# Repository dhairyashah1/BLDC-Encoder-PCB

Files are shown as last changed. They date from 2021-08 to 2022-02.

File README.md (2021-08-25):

# BLDC-Encoder-PCB

This repository contains KiCAD Design Files for Encoder PCB made using AS5600 hall sensor based Encoder Chip for [SRA-VJTI](https://github.com/SRA-VJTI/)'s BLDC Actuator and Quadraped Testing.

## Schematics
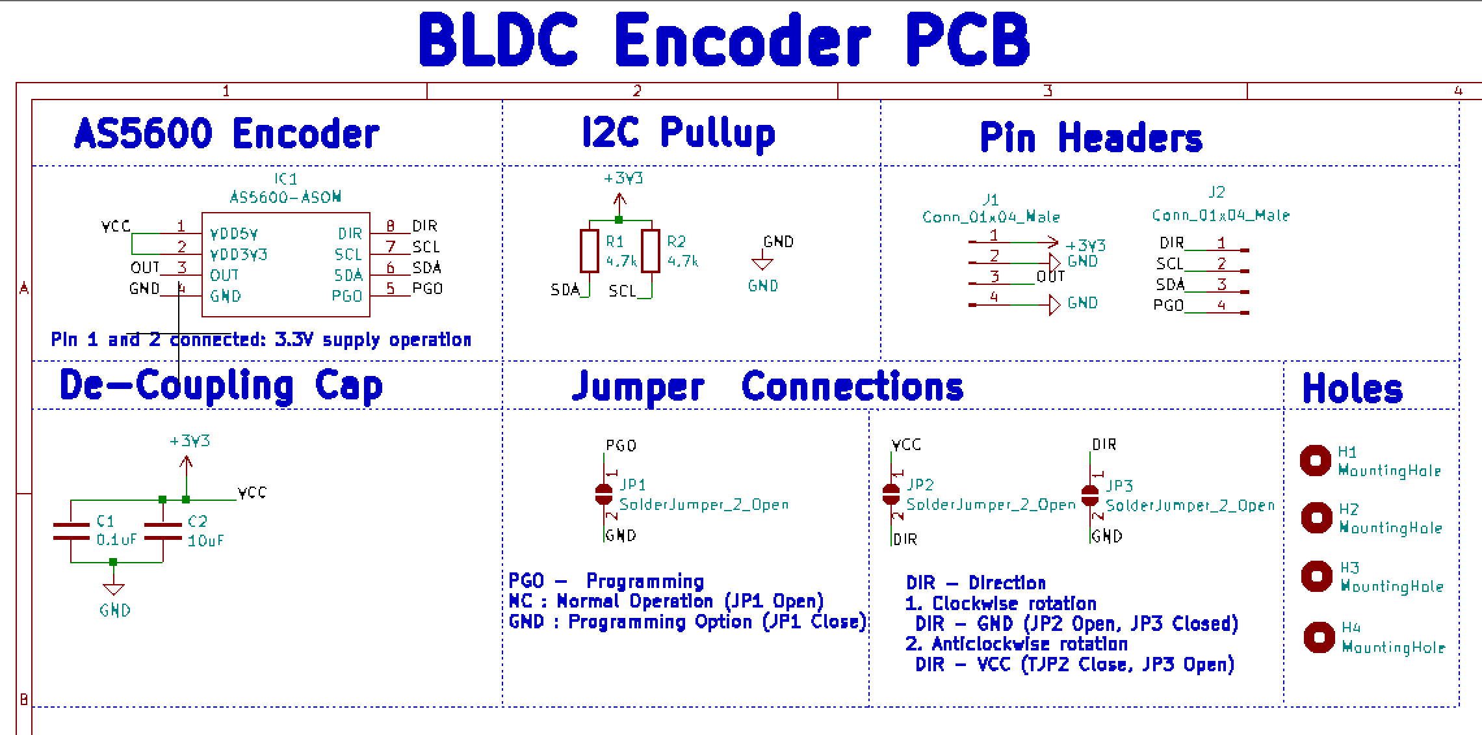
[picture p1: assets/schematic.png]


## Renders

### Front View
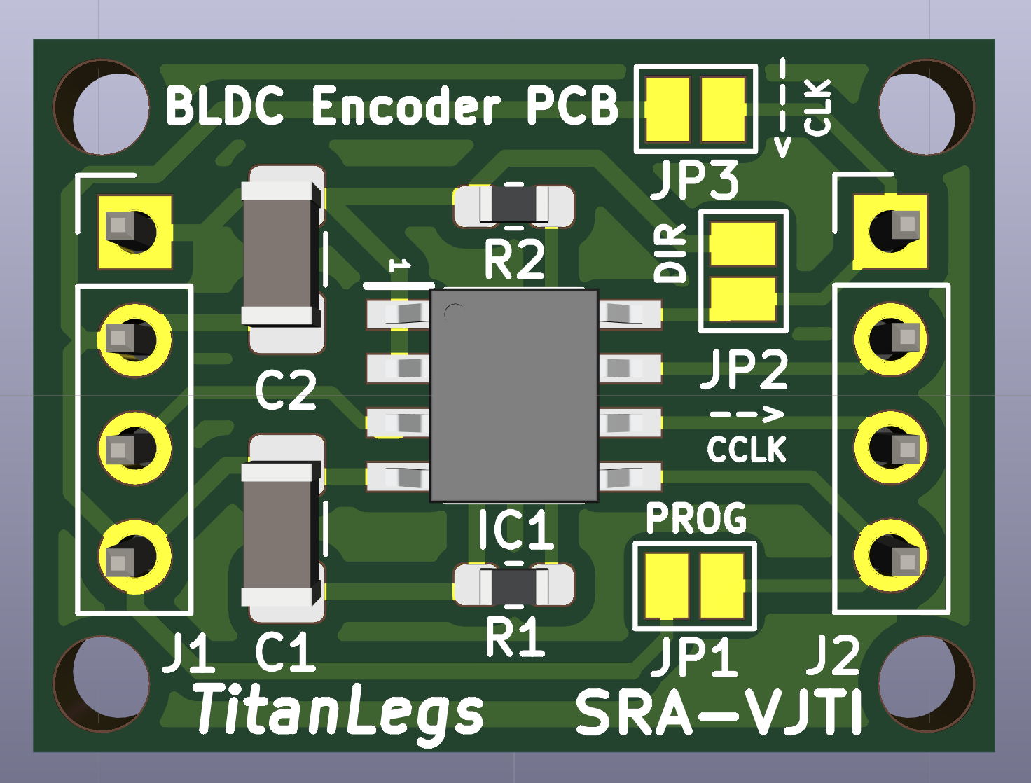
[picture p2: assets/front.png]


### General View
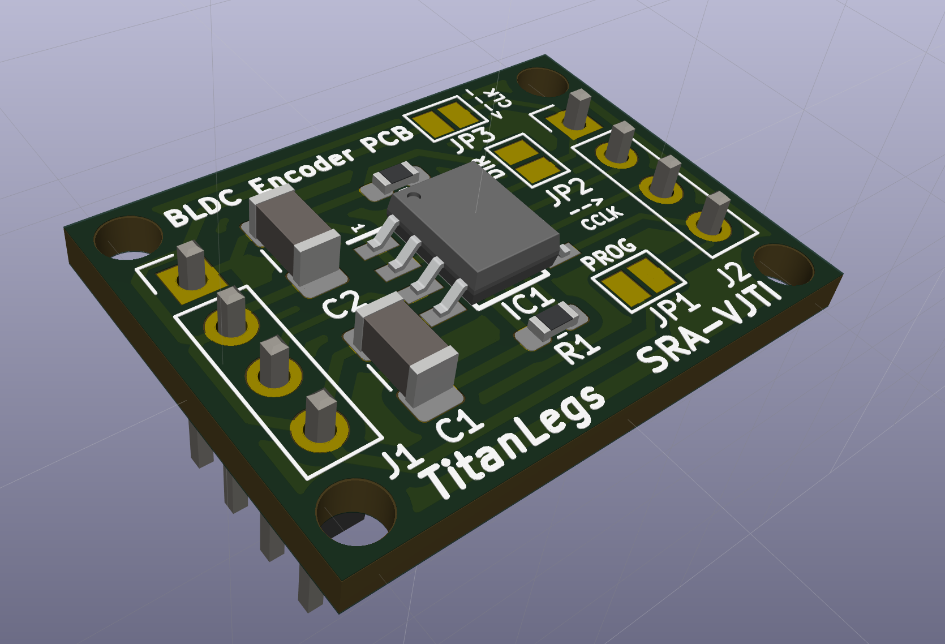
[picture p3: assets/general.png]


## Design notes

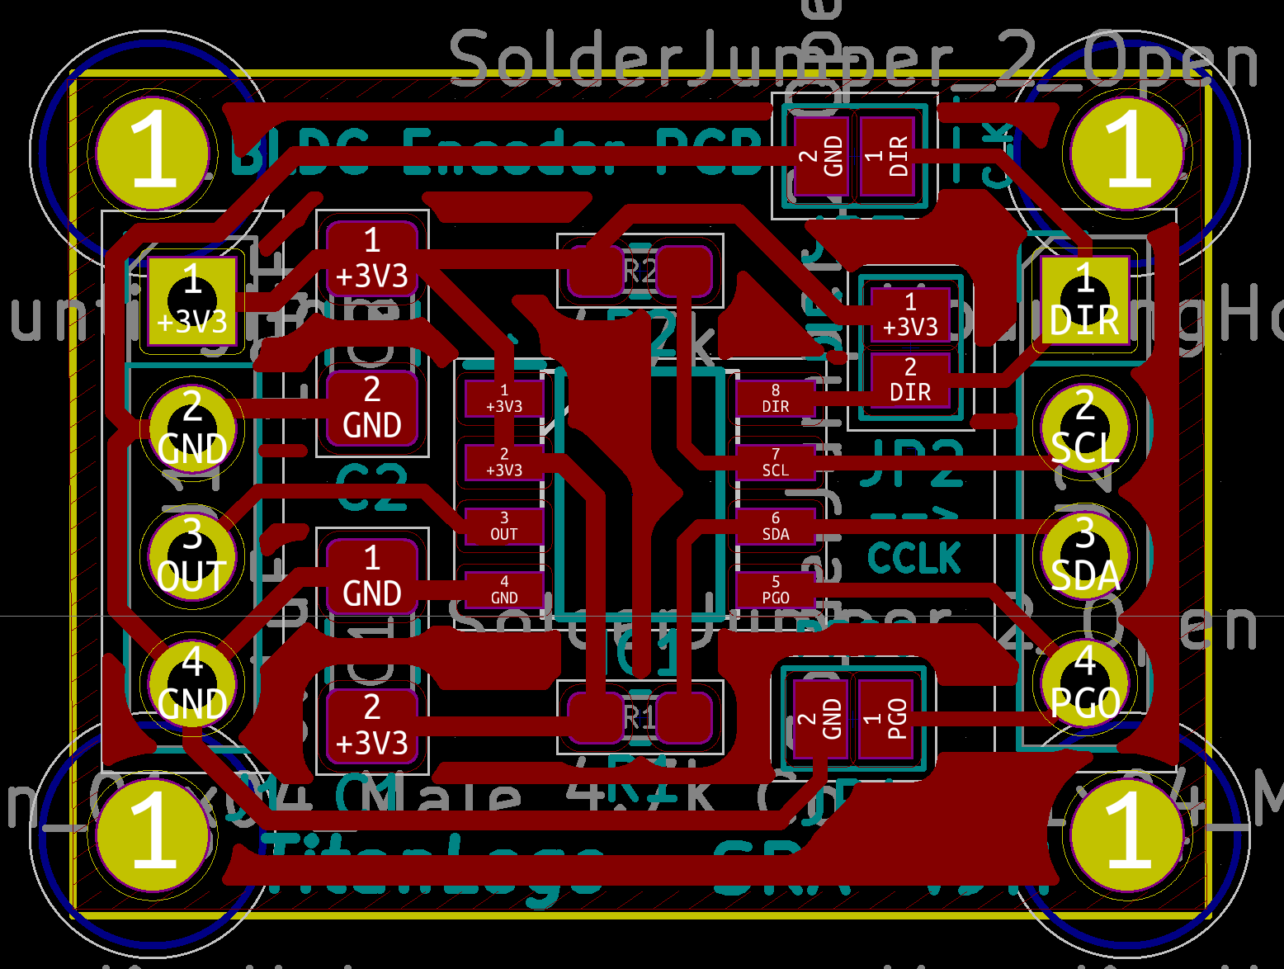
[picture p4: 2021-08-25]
assets/routing.png

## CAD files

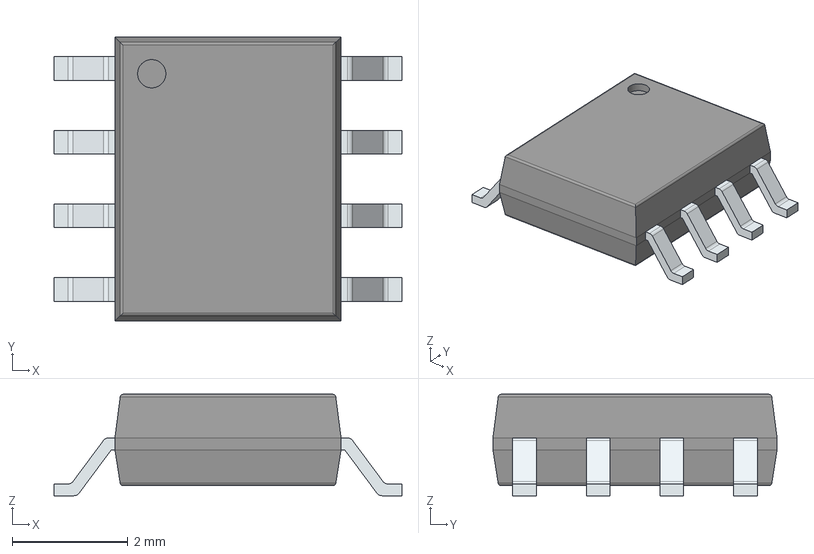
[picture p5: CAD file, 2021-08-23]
component_libraries/AS5600-ASOM/AS5600-ASOM.stp
6.00 x 4.90 x 1.75 mm
PinsArrayLR

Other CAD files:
component_libraries/AS5600-ASOM/AS5600-ASOM.stl

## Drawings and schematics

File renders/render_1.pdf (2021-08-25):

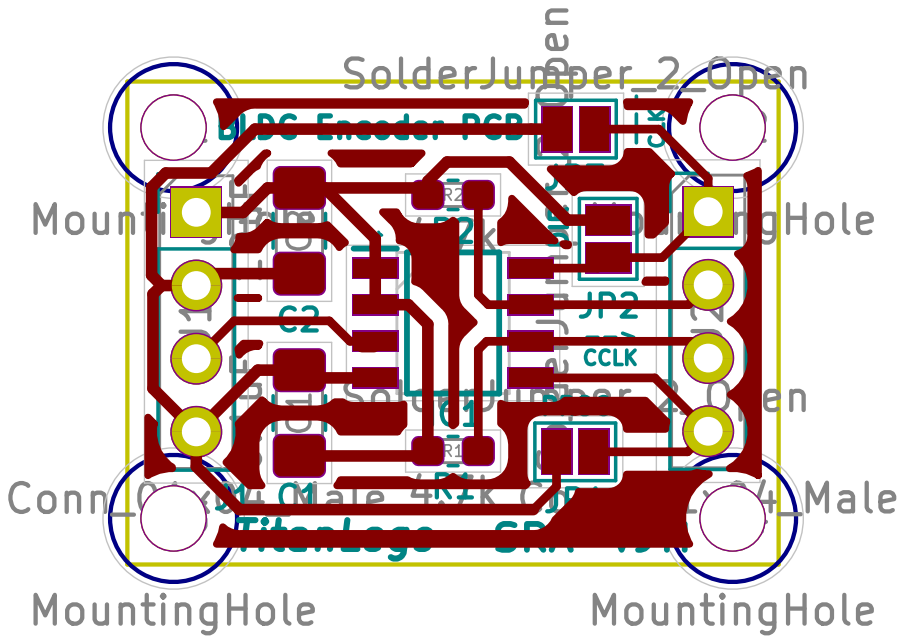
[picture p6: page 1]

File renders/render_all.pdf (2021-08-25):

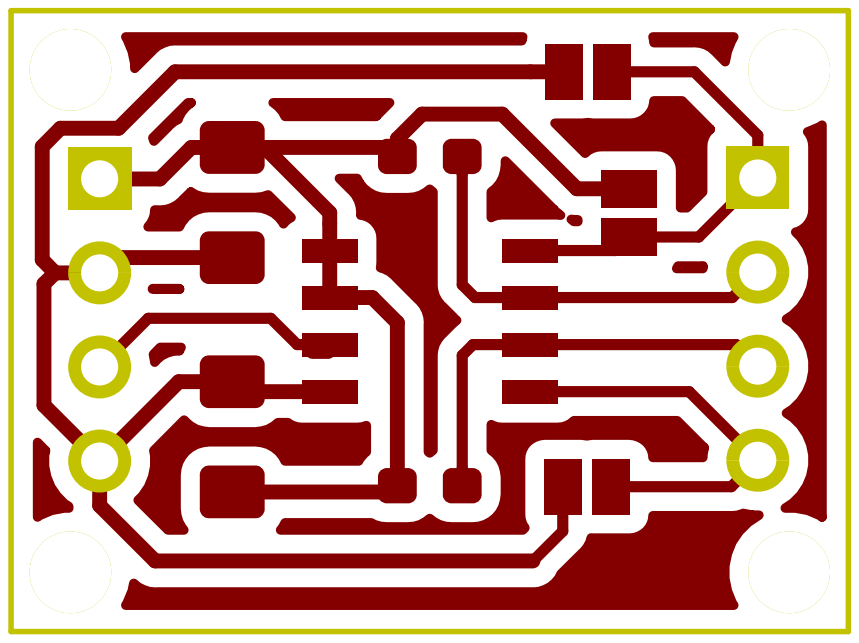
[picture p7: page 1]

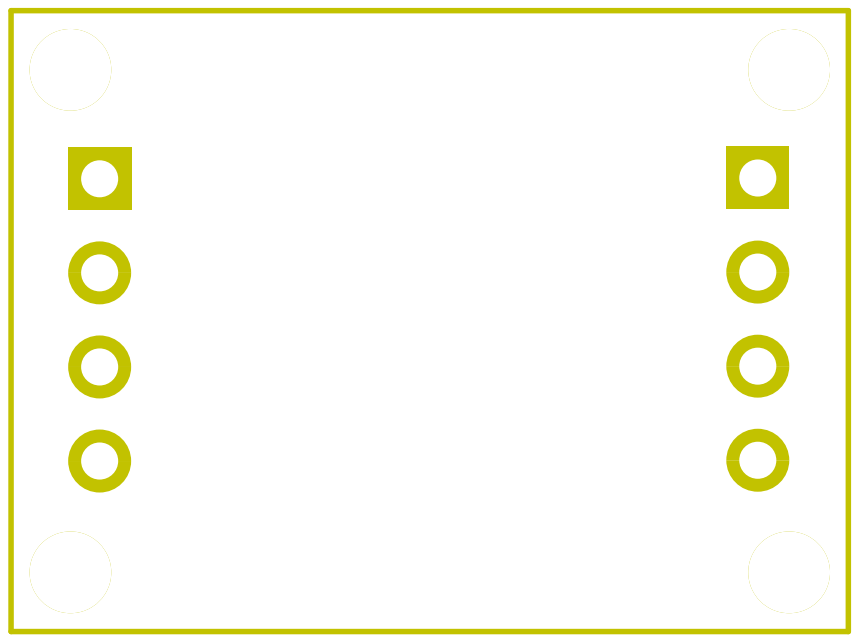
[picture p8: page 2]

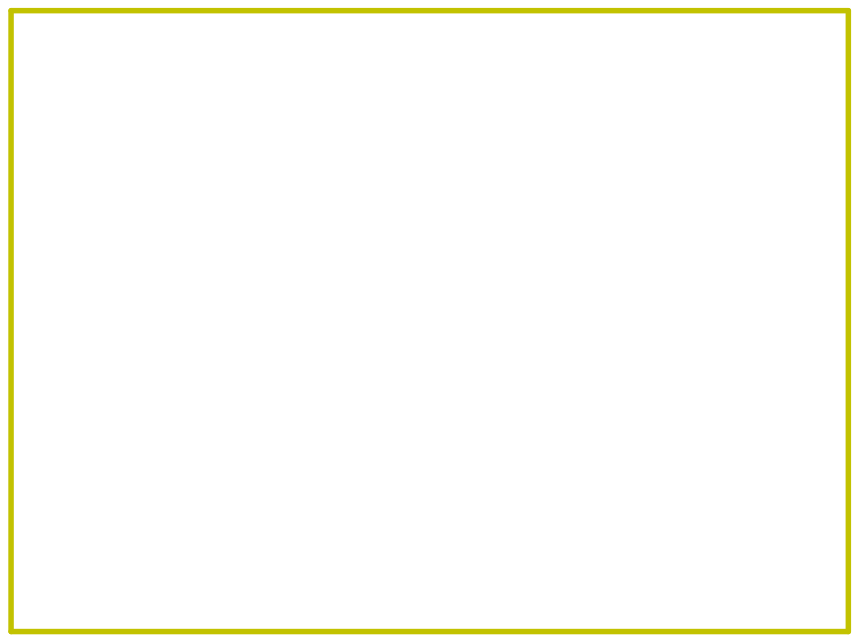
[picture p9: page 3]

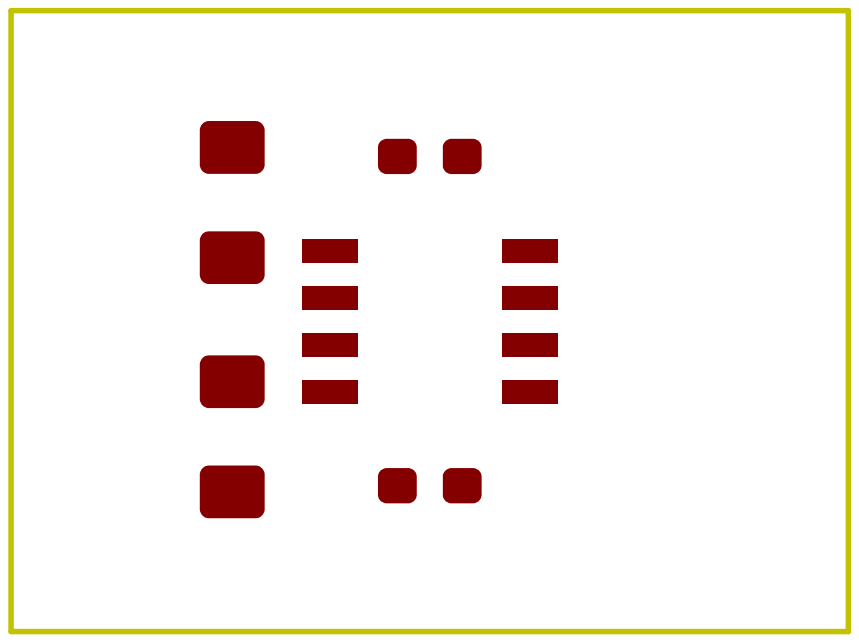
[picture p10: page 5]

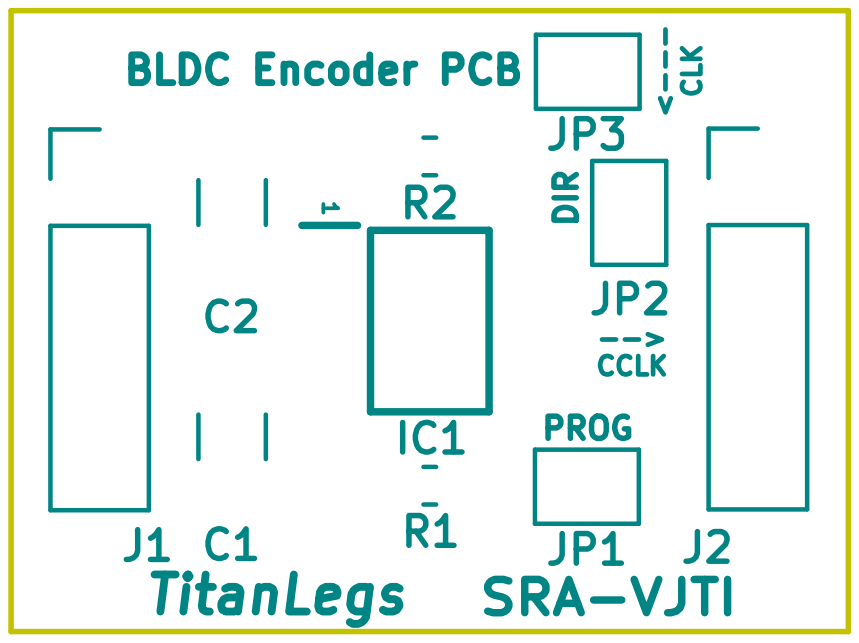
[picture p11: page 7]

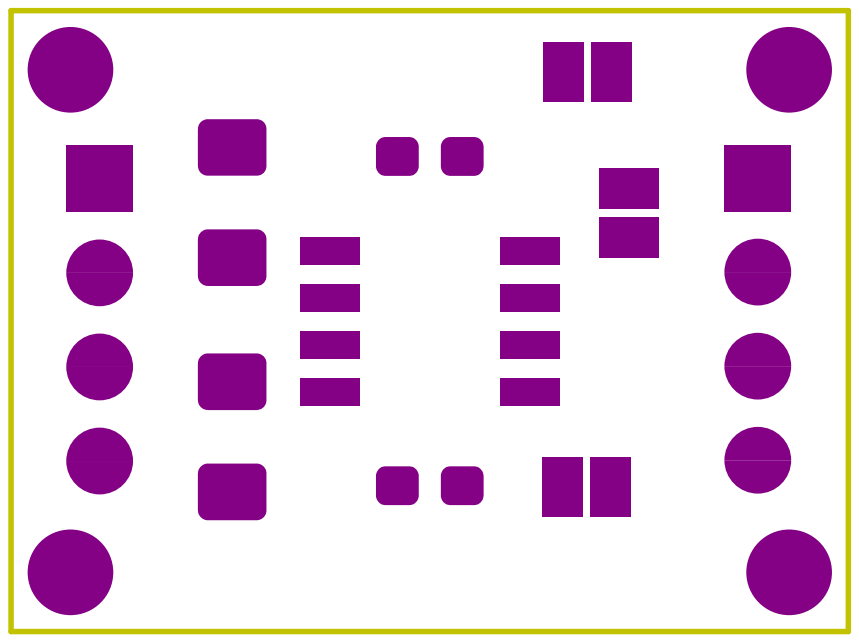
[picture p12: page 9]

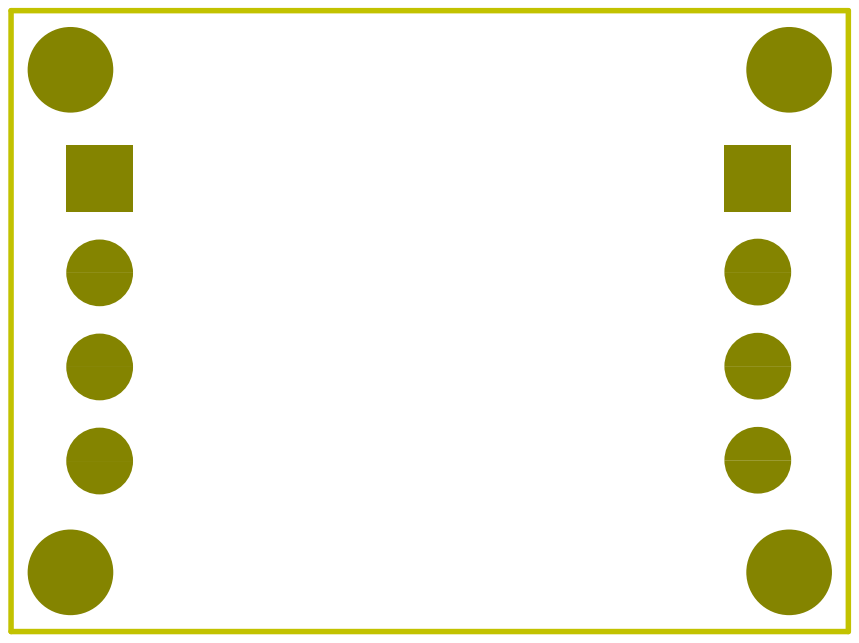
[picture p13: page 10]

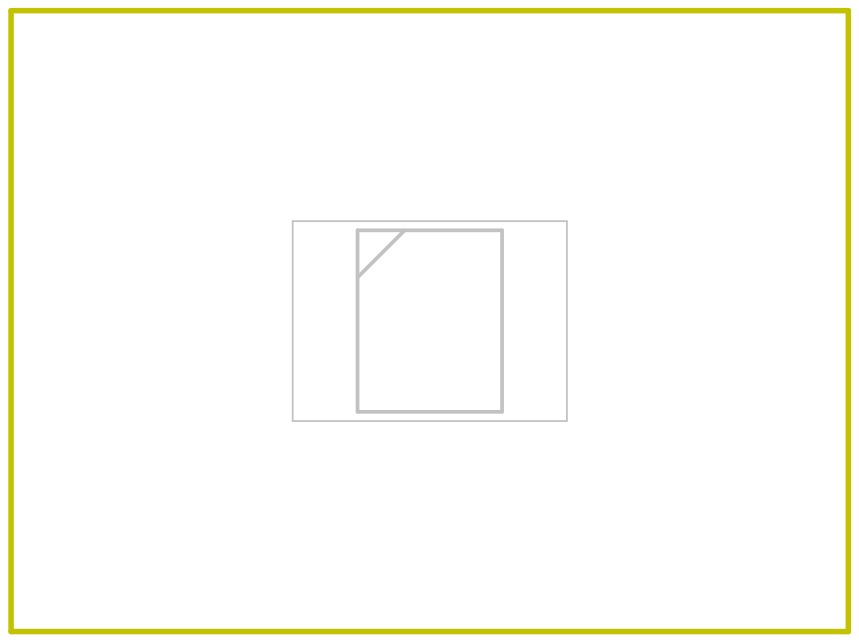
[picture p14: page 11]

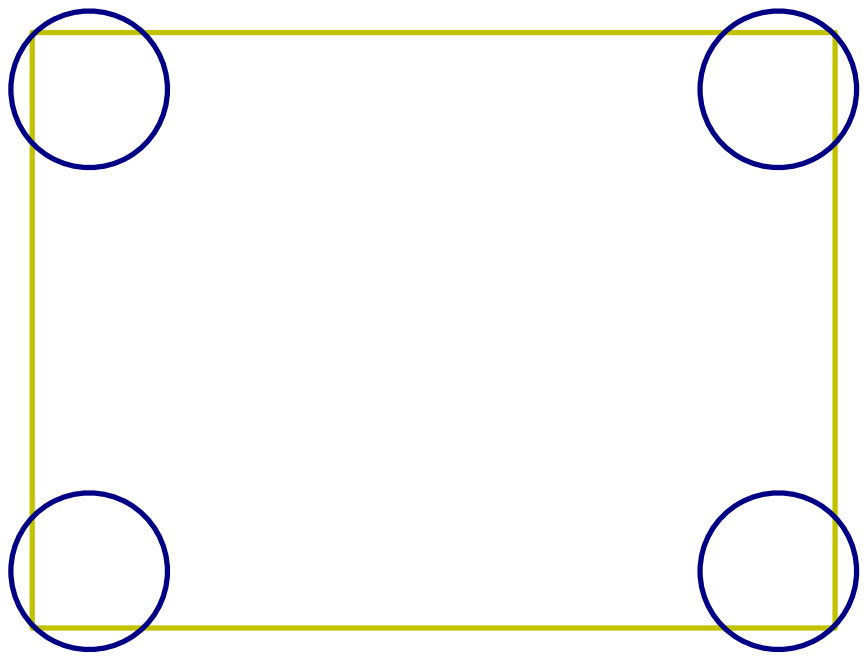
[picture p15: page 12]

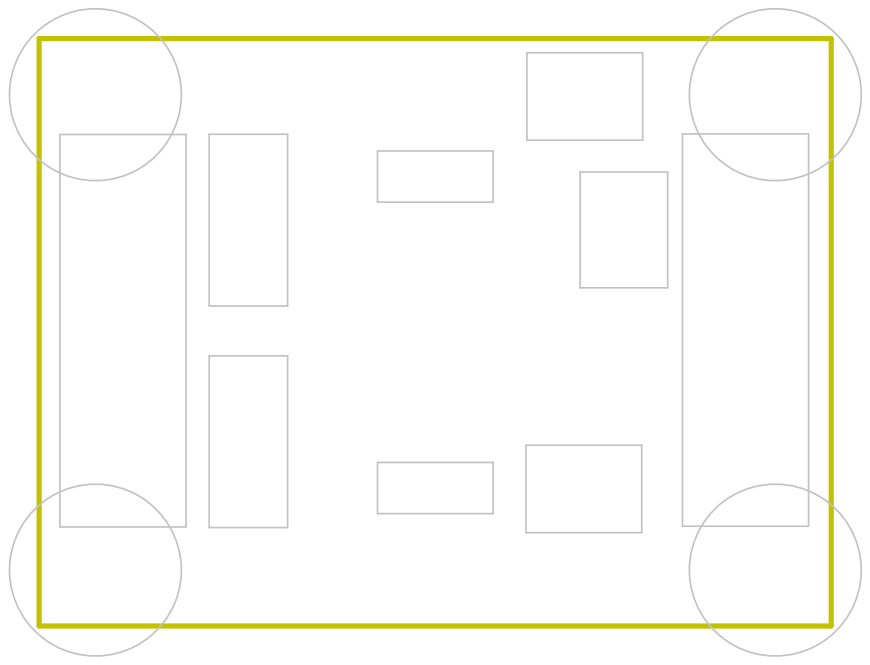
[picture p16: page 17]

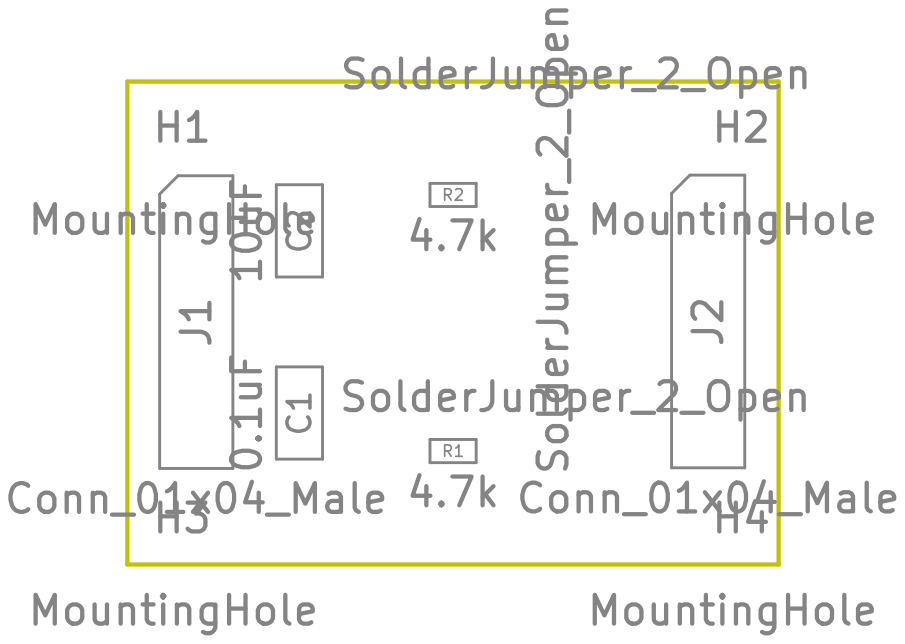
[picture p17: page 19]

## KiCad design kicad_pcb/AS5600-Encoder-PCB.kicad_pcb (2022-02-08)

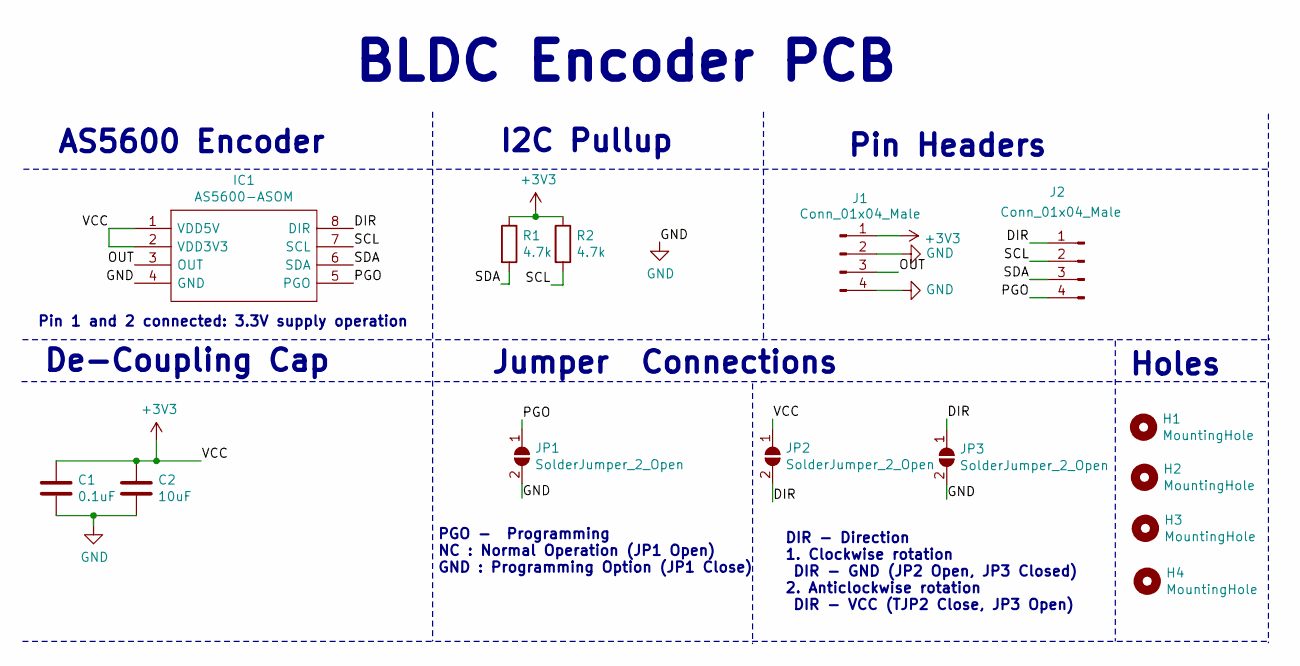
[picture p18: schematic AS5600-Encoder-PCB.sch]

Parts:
C1: 0.1uF; C_1206_3216Metric_Pad1.42x1.75mm_HandSolder
C2: 10uF; C_1206_3216Metric_Pad1.42x1.75mm_HandSolder
H1, H2, H3, H4: MountingHole; MountingHole_2.2mm_M2
IC1: AS5600-ASOM; SOIC127P600X175-8N; Manufacturer_Part_Number AS5600-ASOM; Mouser Part Number 985-AS5600-ASOM
J1, J2: Conn_01x04_Male; PinHeader_1x04_P2.54mm_Vertical
JP1, JP2, JP3: SolderJumper_2_Open; SolderJumper-2_P1.3mm_Open_Pad1.0x1.5mm
R1, R2: 4.7k; R_0603_1608Metric_Pad1.05x0.95mm_HandSolder

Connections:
+3V3: C1.2, C2.1, IC1.1 (VDD5V), IC1.2 (VDD3V3), J1.1, JP2.1 (A), R1.1, R2.1
/DIR: IC1.8 (DIR), J2.1, JP2.2 (B), JP3.1 (A)
/OUT: IC1.3 (OUT), J1.3
/PGO: IC1.5 (PGO), J2.4, JP1.1 (A)
/SCL: IC1.7 (SCL), J2.2, R2.2
/SDA: IC1.6 (SDA), J2.3, R1.2
GND: C1.1, C2.2, IC1.4 (GND), J1.2, J1.4, JP1.2 (B), JP3.2 (B)

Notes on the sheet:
I2C Pullup
Pin Headers
De-Coupling Cap
Jumper Connections
PGO - Programming NC : Normal Operation (JP1 Open) GND : Programming Option (JP1 Close)
Pin 1 and 2 connected: 3.3V supply operation
DIR - Direction 1. Clockwise rotation DIR - GND (JP2 Open, JP3 Closed) 2. Anticlockwise rotation DIR - VCC (TJP2 Close, JP3 Open)
AS5600 Encoder
Holes
BLDC Encoder PCB

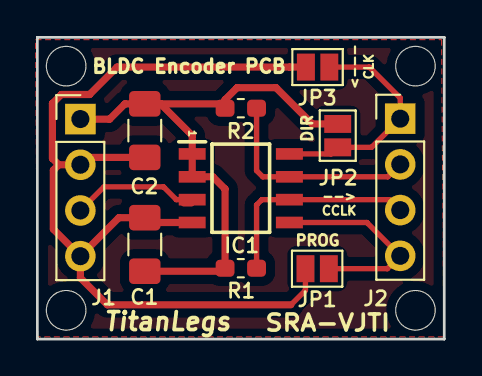
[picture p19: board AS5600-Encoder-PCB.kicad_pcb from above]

Board: 2 copper layers, 22.6 x 16.8 mm, 14 parts (0 on the bottom side), 7 nets.

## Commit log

2021-08-23 Added PTH PCB for AS5600 Encoder Controller
    [AS5600-ASOM.stl, AS5600-ASOM.stp, AS5600-Encoder-PCB.kicad_pcb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]
2021-08-23 Fixed .gitignore
    [AS5600-Encoder-PCB.kicad_pcb]
2021-08-24 Restructured file structure
    [AS5600-Encoder-PCB.kicad_pcb, AS5600-Encoder-PCB.sch]
2021-08-24 Added SMD PCB for AS5600 Controller Board
    [AS5600-Encoder-PCB.kicad_pcb, AS5600-Encoder-PCB.sch]
2021-08-24 Added SMD PCB assets
2021-08-24 Added holes, gerbers - SMD PCB
    [AS5600-Encoder-PCB-B_Cu.gbr, AS5600-Encoder-PCB-B_Mask.gbr, AS5600-Encoder-PCB-B_Paste.gbr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]
2021-08-24 Added Schematic asset
    [AS5600-Encoder-PCB.sch]
2021-08-24 Made suggested changes
    [AS5600-Encoder-PCB-B_Cu.gbr, AS5600-Encoder-PCB-B_Mask.gbr, AS5600-Encoder-PCB-B_Paste.gbr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]
2021-08-25 Modified and optimized design for 1 layer
    [AS5600-Encoder-PCB-B_Cu.gbr, AS5600-Encoder-PCB-B_Mask.gbr, AS5600-Encoder-PCB-B_Paste.gbr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]
2021-08-26 Modified gerbers
2022-02-08 Added PCB layout dimensions
    [AS5600-Encoder-PCB.kicad_pcb]
